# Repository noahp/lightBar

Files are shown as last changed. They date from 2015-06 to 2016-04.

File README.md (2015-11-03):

# lightBar
prototype in action  
Basic serial addressable WS2812B RGB LED banner. Comprised of multiple 12x7 modules.

# hardware
Ordered the boards from dirtypcbs.com, $25 shipped. I received 11 boards (1 bonus!), 22 days turn, pretty nice.  
The basic module contains 84 LEDs arranged in 7 rows of 12 each, and is designed to display 2 monospaced 5x7 pixel characters.  
Several 2-character modules can be connected together to create the full display.  

## schematic
[pdf view](https://github.com/noahp/lightBar/raw/master/hw/lightBar.pdf)

## pcb renders
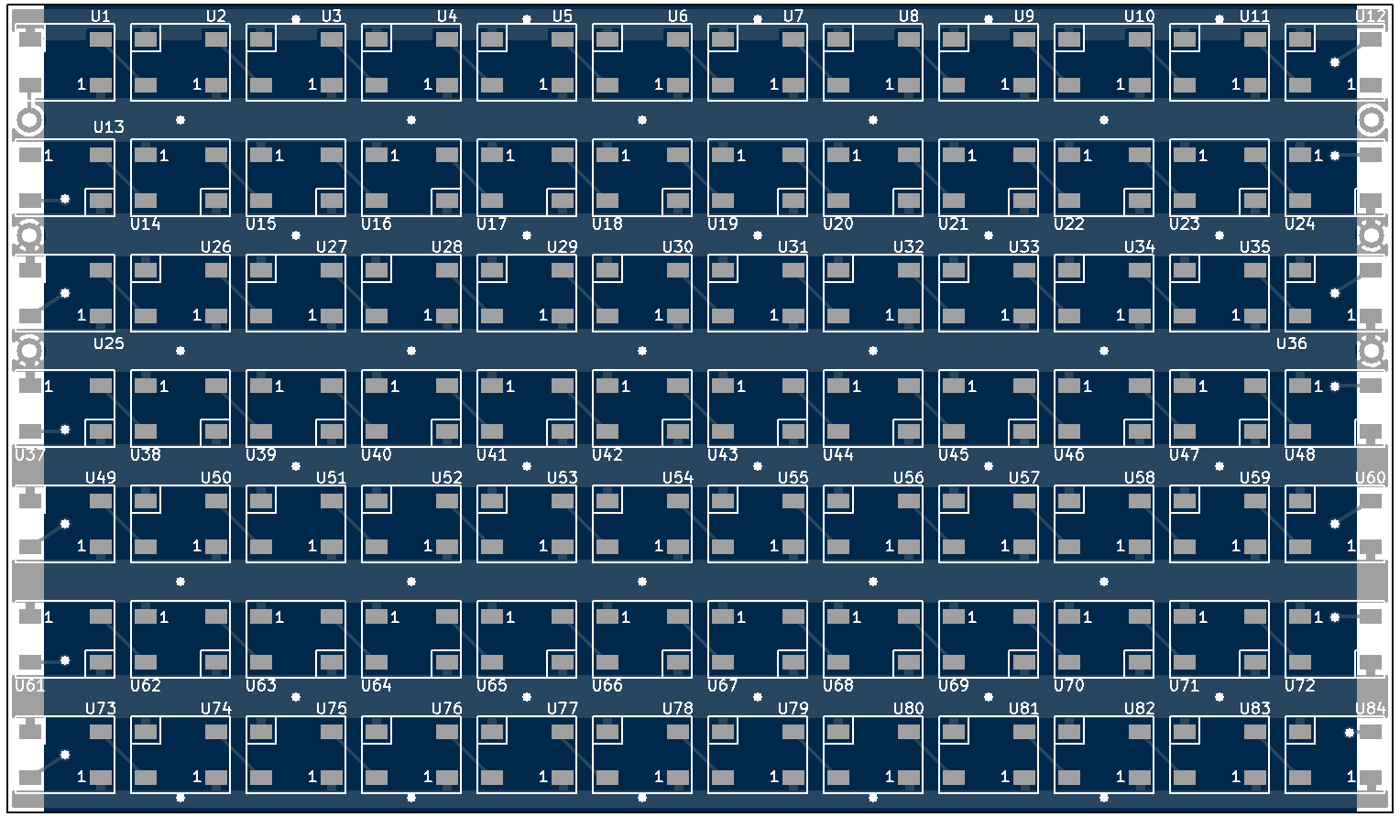
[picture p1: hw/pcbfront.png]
pcb front

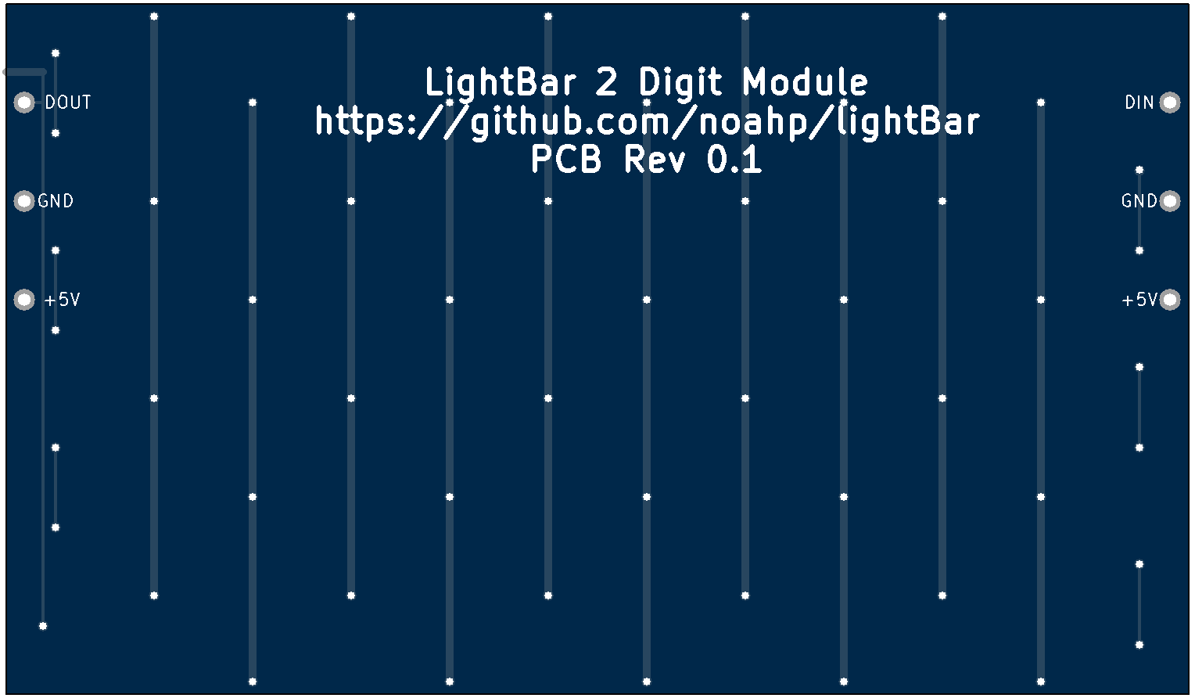
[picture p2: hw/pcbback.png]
pcb back
  

# software
My plan is to use some Cortex-M processor on the strip itself to do the real-time LED control (framebuffer + SPI transmission). Probably an ESP8266 wifi module (ESP-12) will be used as the interface for setting the displayed data.  
Some ideas-  
- get internet time/date and display it
- display weather, possibly using a gradient over the text background showing temperature/precip conditions

I'm thinking some simple description language (maybe JSON format) to transmit the content from the ESP8266 to the LED controller. Something that can describe text content and position, bitmaps, maybe transparency. The LED controller would parse this data into its bitmapped frame buffer and print it on the display.

For operation of the ESP8266, flow would be like this-  
`wakeup->connect to saved access point credentials (lua file system)`  
`    ->success, get time and date and weather information->sleep`  
`    ->failure after few seconds, switch to access point mode and serve simple web page form with 2 fields, for ssid + key->if HTTP POSTs new credentials->back to start (try to connect)`

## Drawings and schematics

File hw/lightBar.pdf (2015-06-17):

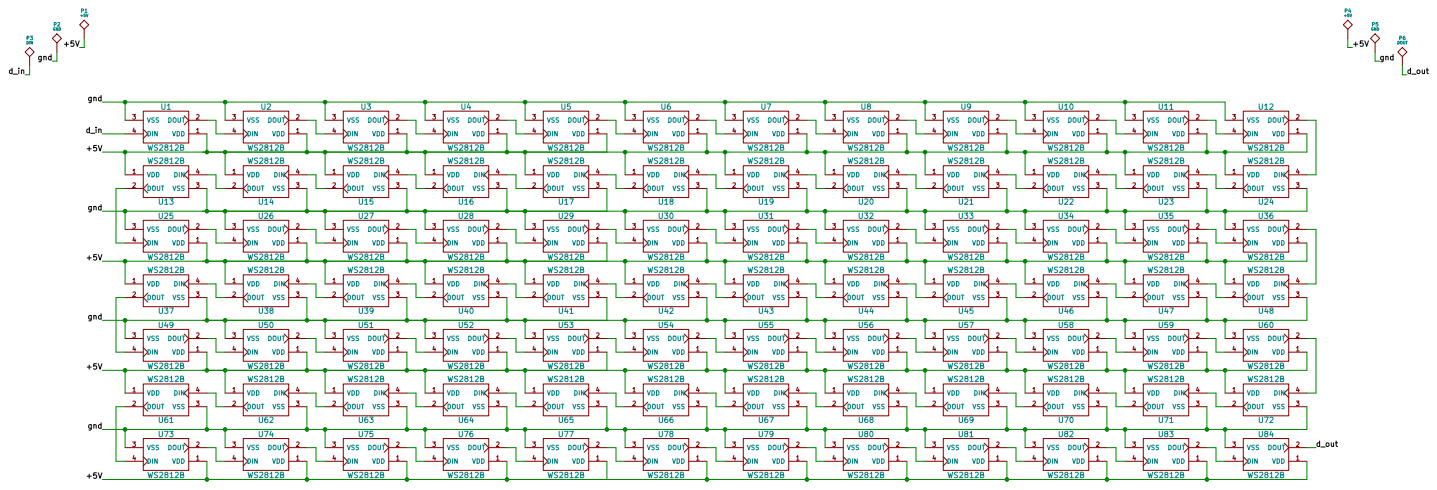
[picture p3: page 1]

File: lightBar.sch Sheet: /

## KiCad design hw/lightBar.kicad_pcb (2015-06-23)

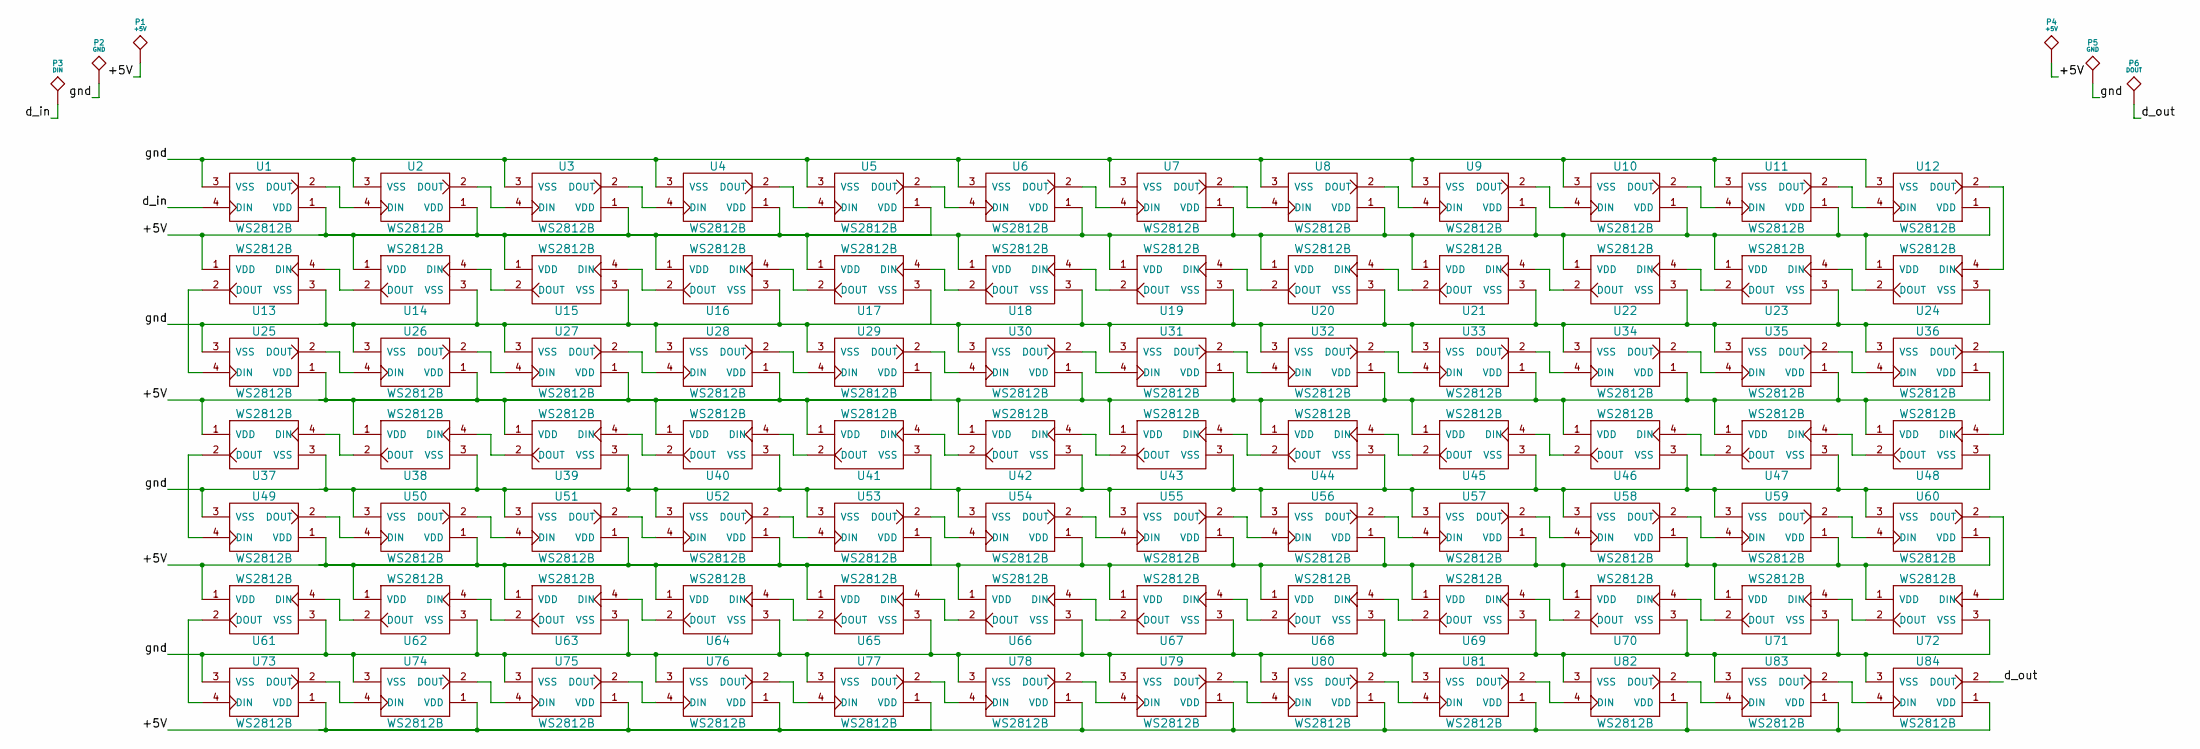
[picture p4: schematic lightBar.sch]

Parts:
P1, P4: +5V; TEST_0.100
P2, P5: GND; TEST_0.100
P3: DIN; TEST_0.100
P6: DOUT; TEST_0.100
U1, U2, U3, U4, U5, U6, U7, U8, U9, U10, U11, U12, U13, U14, U15, U16, U17, U18, U19, U20, U21, U22, U23, U24, U25, U26, U27, U28, U29, U30, U31, U32, U33, U34, U35, U36, U37, U38, U39, U40, U41, U42, U43, U44, U45, U46, U47, U48, U49, U50, U51, U52, U53, U54, U55, U56, U57, U58, U59, U60, U61, U62, U63, U64, U65, U66, U67, U68, U69, U70, U71, U72, U73, U74, U75, U76, U77, U78, U79, U80, U81, U82, U83, U84: WS2812B; WS2812B_SMD_5050

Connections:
/+5V: P1.1, P4.1, U1.1 (VDD), U2.1 (VDD), U3.1 (VDD), U4.1 (VDD), U5.1 (VDD), U6.1 (VDD), U7.1 (VDD), U8.1 (VDD), U9.1 (VDD), U10.1 (VDD), U11.1 (VDD), U12.1 (VDD), U13.1 (VDD), U14.1 (VDD), U15.1 (VDD), U16.1 (VDD), U17.1 (VDD), U18.1 (VDD), U19.1 (VDD), U20.1 (VDD), U21.1 (VDD), U22.1 (VDD), U23.1 (VDD), U24.1 (VDD), U25.1 (VDD), U26.1 (VDD), U27.1 (VDD), U28.1 (VDD), U29.1 (VDD), U30.1 (VDD), U31.1 (VDD), U32.1 (VDD), U33.1 (VDD), U34.1 (VDD), U35.1 (VDD), U36.1 (VDD), U37.1 (VDD), U38.1 (VDD), U39.1 (VDD), U40.1 (VDD), U41.1 (VDD), U42.1 (VDD), U43.1 (VDD), U44.1 (VDD), U45.1 (VDD), U46.1 (VDD), U47.1 (VDD), U48.1 (VDD), U49.1 (VDD), U50.1 (VDD), U51.1 (VDD), U52.1 (VDD), U53.1 (VDD), U54.1 (VDD), U55.1 (VDD), U56.1 (VDD), U57.1 (VDD), U58.1 (VDD), U59.1 (VDD), U60.1 (VDD), U61.1 (VDD), U62.1 (VDD), U63.1 (VDD), U64.1 (VDD), U65.1 (VDD), U66.1 (VDD), U67.1 (VDD), U68.1 (VDD), U69.1 (VDD), U70.1 (VDD), U71.1 (VDD), U72.1 (VDD), U73.1 (VDD), U74.1 (VDD), U75.1 (VDD), U76.1 (VDD), U77.1 (VDD), U78.1 (VDD), U79.1 (VDD), U80.1 (VDD), U81.1 (VDD), U82.1 (VDD), U83.1 (VDD), U84.1 (VDD)
/d_in: P3.1, U1.4 (DIN)
/d_out: P6.1, U84.2 (DOUT)
/gnd: P2.1, P5.1, U1.3 (VSS), U2.3 (VSS), U3.3 (VSS), U4.3 (VSS), U5.3 (VSS), U6.3 (VSS), U7.3 (VSS), U8.3 (VSS), U9.3 (VSS), U10.3 (VSS), U11.3 (VSS), U12.3 (VSS), U13.3 (VSS), U14.3 (VSS), U15.3 (VSS), U16.3 (VSS), U17.3 (VSS), U18.3 (VSS), U19.3 (VSS), U20.3 (VSS), U21.3 (VSS), U22.3 (VSS), U23.3 (VSS), U24.3 (VSS), U25.3 (VSS), U26.3 (VSS), U27.3 (VSS), U28.3 (VSS), U29.3 (VSS), U30.3 (VSS), U31.3 (VSS), U32.3 (VSS), U33.3 (VSS), U34.3 (VSS), U35.3 (VSS), U36.3 (VSS), U37.3 (VSS), U38.3 (VSS), U39.3 (VSS), U40.3 (VSS), U41.3 (VSS), U42.3 (VSS), U43.3 (VSS), U44.3 (VSS), U45.3 (VSS), U46.3 (VSS), U47.3 (VSS), U48.3 (VSS), U49.3 (VSS), U50.3 (VSS), U51.3 (VSS), U52.3 (VSS), U53.3 (VSS), U54.3 (VSS), U55.3 (VSS), U56.3 (VSS), U57.3 (VSS), U58.3 (VSS), U59.3 (VSS), U60.3 (VSS), U61.3 (VSS), U62.3 (VSS), U63.3 (VSS), U64.3 (VSS), U65.3 (VSS), U66.3 (VSS), U67.3 (VSS), U68.3 (VSS), U69.3 (VSS), U70.3 (VSS), U71.3 (VSS), U72.3 (VSS), U73.3 (VSS), U74.3 (VSS), U75.3 (VSS), U76.3 (VSS), U77.3 (VSS), U78.3 (VSS), U79.3 (VSS), U80.3 (VSS), U81.3 (VSS), U82.3 (VSS), U83.3 (VSS), U84.3 (VSS)
unnamed: U1.2 (DOUT), U2.4 (DIN)
unnamed: U2.2 (DOUT), U3.4 (DIN)
unnamed: U3.2 (DOUT), U4.4 (DIN)
unnamed: U4.2 (DOUT), U5.4 (DIN)
unnamed: U5.2 (DOUT), U6.4 (DIN)
unnamed: U6.2 (DOUT), U7.4 (DIN)
unnamed: U7.2 (DOUT), U8.4 (DIN)
unnamed: U8.2 (DOUT), U9.4 (DIN)
unnamed: U10.2 (DOUT), U11.4 (DIN)
unnamed: U9.2 (DOUT), U10.4 (DIN)
unnamed: U11.2 (DOUT), U12.4 (DIN)
unnamed: U12.2 (DOUT), U24.4 (DIN)
unnamed: U13.2 (DOUT), U25.4 (DIN)
unnamed: U13.4 (DIN), U14.2 (DOUT)
unnamed: U14.4 (DIN), U15.2 (DOUT)
unnamed: U15.4 (DIN), U16.2 (DOUT)
unnamed: U16.4 (DIN), U17.2 (DOUT)
unnamed: U17.4 (DIN), U18.2 (DOUT)
unnamed: U18.4 (DIN), U19.2 (DOUT)
unnamed: U19.4 (DIN), U20.2 (DOUT)
unnamed: U20.4 (DIN), U21.2 (DOUT)
unnamed: U21.4 (DIN), U22.2 (DOUT)
unnamed: U22.4 (DIN), U23.2 (DOUT)
unnamed: U23.4 (DIN), U24.2 (DOUT)
unnamed: U25.2 (DOUT), U26.4 (DIN)
unnamed: U26.2 (DOUT), U27.4 (DIN)
unnamed: U27.2 (DOUT), U28.4 (DIN)
unnamed: U28.2 (DOUT), U29.4 (DIN)
unnamed: U29.2 (DOUT), U30.4 (DIN)
unnamed: U30.2 (DOUT), U31.4 (DIN)
unnamed: U31.2 (DOUT), U32.4 (DIN)
unnamed: U32.2 (DOUT), U33.4 (DIN)
unnamed: U33.2 (DOUT), U34.4 (DIN)
unnamed: U34.2 (DOUT), U35.4 (DIN)
unnamed: U35.2 (DOUT), U36.4 (DIN)
unnamed: U36.2 (DOUT), U48.4 (DIN)
unnamed: U37.2 (DOUT), U49.4 (DIN)
unnamed: U37.4 (DIN), U38.2 (DOUT)
unnamed: U38.4 (DIN), U39.2 (DOUT)
unnamed: U39.4 (DIN), U40.2 (DOUT)
unnamed: U40.4 (DIN), U41.2 (DOUT)
unnamed: U41.4 (DIN), U42.2 (DOUT)
unnamed: U42.4 (DIN), U43.2 (DOUT)
unnamed: U43.4 (DIN), U44.2 (DOUT)
unnamed: U44.4 (DIN), U45.2 (DOUT)
unnamed: U45.4 (DIN), U46.2 (DOUT)
unnamed: U46.4 (DIN), U47.2 (DOUT)
unnamed: U47.4 (DIN), U48.2 (DOUT)
unnamed: U49.2 (DOUT), U50.4 (DIN)
unnamed: U50.2 (DOUT), U51.4 (DIN)
unnamed: U51.2 (DOUT), U52.4 (DIN)
unnamed: U52.2 (DOUT), U53.4 (DIN)
unnamed: U53.2 (DOUT), U54.4 (DIN)
unnamed: U54.2 (DOUT), U55.4 (DIN)
unnamed: U55.2 (DOUT), U56.4 (DIN)
unnamed: U56.2 (DOUT), U57.4 (DIN)
unnamed: U57.2 (DOUT), U58.4 (DIN)
unnamed: U58.2 (DOUT), U59.4 (DIN)
unnamed: U59.2 (DOUT), U60.4 (DIN)
unnamed: U60.2 (DOUT), U72.4 (DIN)
unnamed: U61.2 (DOUT), U73.4 (DIN)
unnamed: U61.4 (DIN), U62.2 (DOUT)
unnamed: U62.4 (DIN), U63.2 (DOUT)
unnamed: U63.4 (DIN), U64.2 (DOUT)
unnamed: U64.4 (DIN), U65.2 (DOUT)
unnamed: U65.4 (DIN), U66.2 (DOUT)
unnamed: U66.4 (DIN), U67.2 (DOUT)
unnamed: U67.4 (DIN), U68.2 (DOUT)
unnamed: U68.4 (DIN), U69.2 (DOUT)
unnamed: U69.4 (DIN), U70.2 (DOUT)
unnamed: U70.4 (DIN), U71.2 (DOUT)
unnamed: U71.4 (DIN), U72.2 (DOUT)
unnamed: U73.2 (DOUT), U74.4 (DIN)
unnamed: U74.2 (DOUT), U75.4 (DIN)
unnamed: U75.2 (DOUT), U76.4 (DIN)
unnamed: U76.2 (DOUT), U77.4 (DIN)
unnamed: U77.2 (DOUT), U78.4 (DIN)
unnamed: U78.2 (DOUT), U79.4 (DIN)
unnamed: U79.2 (DOUT), U80.4 (DIN)
unnamed: U80.2 (DOUT), U81.4 (DIN)
unnamed: U81.2 (DOUT), U82.4 (DIN)
unnamed: U82.2 (DOUT), U83.4 (DIN)
unnamed: U83.2 (DOUT), U84.4 (DIN)

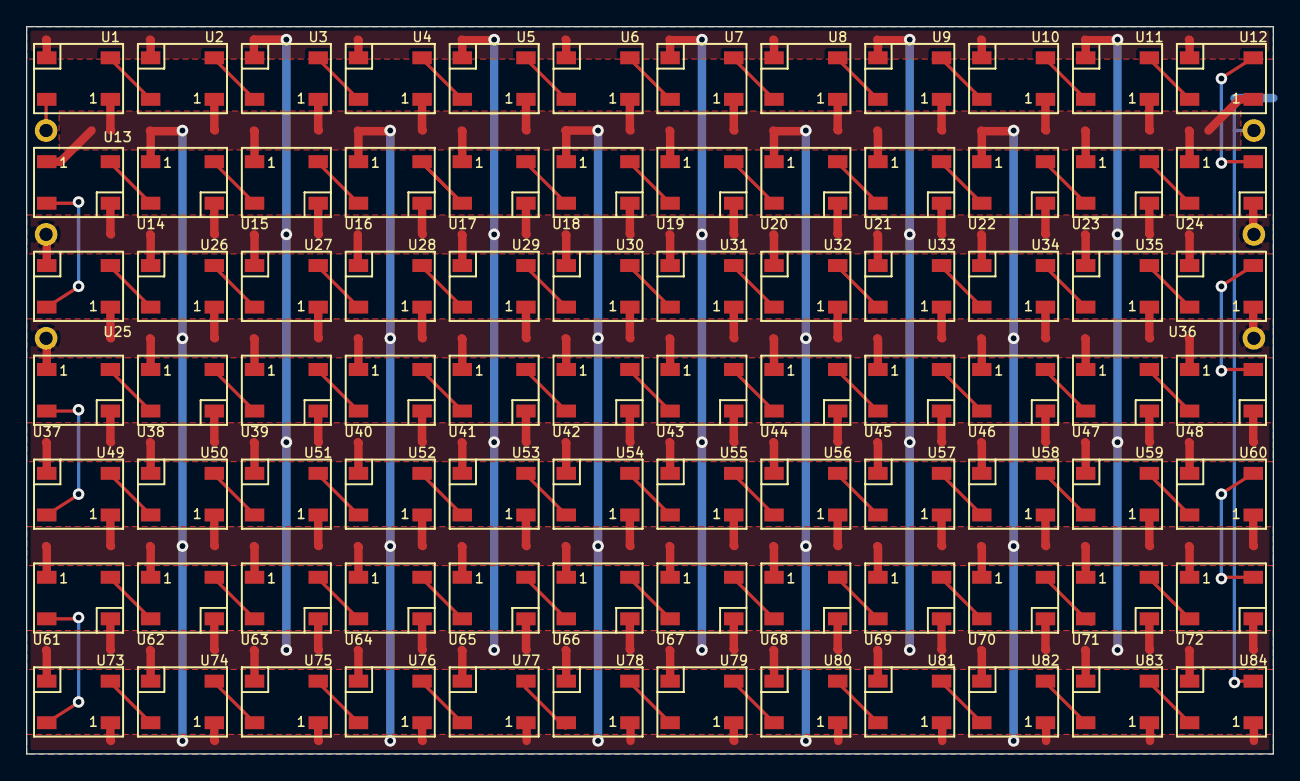
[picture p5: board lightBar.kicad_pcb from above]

Board: 2 copper layers, 96.0 x 56.0 mm, 90 parts (0 on the bottom side), 87 nets.

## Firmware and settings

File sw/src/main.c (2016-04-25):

#include "MKL26Z4.h"
#include "systick.h"
#include <string.h> // memset
#include "usb_main.h"
#include <stdlib.h> // strtoul
#include <stdbool.h>
#include "rgb_mgr.h"

#include <stdarg.h>
#include <stdio.h>
#include <stdlib.h>
#include <errno.h>

// makes heap go
caddr_t
_sbrk (int incr)
{
  extern char   end __asm ("end");
  extern char   heap_limit __asm ("__HeapLimit");
  static char * heap_end;
  char *        prev_heap_end;

  if (heap_end == NULL)
    heap_end = & end;

  prev_heap_end = heap_end;

  if (heap_end + incr > &heap_limit)
    {
#ifdef NIO_ENOMEM   //TODO: Update NIO error code for MQX
        errno = NIO_ENOMEM;
#else
        errno = ENOMEM;
#endif
      return (caddr_t) -1;
    }

  heap_end += incr;

  return (caddr_t) prev_heap_end;
}

// dead area, used as reset pulse in 1-wire ws2812 interface
#define SPI_DEAD_PULSE_LENGTH 260
static uint8_t spiData[SPI_DEAD_PULSE_LENGTH + 3 * 3 * RGB_MGR_PANEL_COUNT *
                       RGB_MGR_LEDS_PER_PANEL];

static void main_init_io(void)
{
  // init ports
  // disable COP
  SIM_COPC = 0;

  // enable clocks for PORTB
  SIM_SCGC5 |= SIM_SCGC5_PORTB_MASK;

  // set B0 to GPIO
  PORTB_PCR0 = PORT_PCR_MUX(1);

  // set output B0 low (LED on initially)
  GPIOB_PCOR = (1 << 0);

  // set B0 DDR to output
  GPIOB_PDDR |= (1 << 0);
}

// static void delay_ms(uint32_t ms)
// {
//    uint32_t start = systick_getms();
//    while(systick_getms() - start < ms);
// }

static void main_init_uart(void)
{
  uint32_t baud;

  // init uart0
  // enable clocks for port a and uart0
  SIM_SCGC5 |= SIM_SCGC5_PORTA_MASK;
  SIM_SCGC4 |= SIM_SCGC4_UART0_MASK;
  SIM_SOPT2 |= SIM_SOPT2_UART0SRC(1); // select MCGFLLCLK clock

  // configure io pins for uart0- alt 2
  PORTA_PCR1 = PORT_PCR_MUX(2);
  PORTA_PCR2 = PORT_PCR_MUX(2);

  // set output mode for TX, pa12
  GPIOA_PDDR |= (1 << 2);

  // set oversampling ratio to 25
  UART0_C4 = UART0_C4_OSR(25 - 1);

  // set baud rate to 9600
  baud      = (48000000 / 9600) / 25;            // <- baud = CLOCK /
                                                 // ((OSR+1)*BR)
  UART0_BDH = UART0_BDH_SBR((baud >> 8) & 0x1F); // upper 5 bits
  UART0_BDL = UART0_BDL_SBR(baud & 0xFF);        // lower 8 bits

  // turn on tx + rx
  UART0_C2 = UART0_C2_RE_MASK | UART0_C2_TE_MASK;

  //    // send a char?
  //    UART0_D = 'N';
}

static void main_init_spi(void)
{
  // init spi0
  // enable clocks for PORTC
  SIM_SCGC5 |= SIM_SCGC5_PORTC_MASK;

  // configure io pins for spi- alt 2
  // PTC4-5-6
  PORTC_PCR4 = PORT_PCR_MUX(2);
  PORTC_PCR5 = PORT_PCR_MUX(2);
  PORTC_PCR6 = PORT_PCR_MUX(2);

  // set pc6 to output-
  GPIOC_PDDR |= (1 << 6);

  // enable SPI0 module
  SIM_SCGC4 |= SIM_SCGC4_SPI0_MASK;

  // configure as master, cs output driven automatically, CPOL=1
  SPI0_C1 |= (SPI_C1_MSTR_MASK | SPI_C1_SSOE_MASK | SPI_C1_CPOL_MASK);
  SPI0_C2 |= SPI_C2_MODFEN_MASK;

  // select clock divider- SPPR = 0b010 (/3), SPR = 0b0010 (/8).
  // target baud rate is 2MHz
  SPI0_BR = SPI_BR_SPPR(0x4) | SPI_BR_SPR(0x0);

  // turn on spi
  SPI0_C1 |= SPI_C1_SPE_MASK;

  // now set up dma
  SIM_SCGC6 |= SIM_SCGC6_DMAMUX_MASK; // enable clocks
  SIM_SCGC7 |= SIM_SCGC7_DMA_MASK;

  // dma mux
  // disable dmamux0 & clear channel select
  DMAMUX0_BASE_PTR->CHCFG[0] &=
    ~(DMAMUX_CHCFG_ENBL_MASK | DMAMUX_CHCFG_SOURCE_MASK);

  // select channel 17 for spi tx & enable it
  DMAMUX0_BASE_PTR->CHCFG[0] |= DMAMUX_CHCFG_SOURCE(17) | DMAMUX_CHCFG_ENBL_MASK;

  // dma
  // set destination address register to the SPI tx register
  DMA_BASE_PTR->DMA[0].DAR = (uint32_t)&SPI0_DL;

  // configure DMA_0 for spi tx
  DMA_BASE_PTR->DMA[0].DCR = DMA_DCR_ERQ_MASK | // enable periph. request
                             DMA_DCR_CS_MASK |
                             DMA_DCR_SINC_MASK |
                             DMA_DCR_SSIZE(0x01) |
                             DMA_DCR_DSIZE(0x01) |
                             DMA_DCR_D_REQ_MASK;
}

static void main_spi_send(uint8_t *pData, uint32_t len)
{
  // wait until dma busy flag is cleared
  while (DMA_BASE_PTR->DMA[0].DSR_BCR & DMA_DSR_BCR_BSY_MASK) ;

  //    // pull spi mosi low (p27) for at least 50us
  //    PORTC_PCR6 = PORT_PCR_MUX(1);
  //    GPIOC_PCOR = (1 << 6);
  //    delay_ms(2);
  // reset dma
  DMA_BASE_PTR->DMA[0].DSR_BCR = DMA_DSR_BCR_DONE_MASK;

  // write to the dma
  DMA_BASE_PTR->DMA[0].SAR     = (uint32_t)pData;
  DMA_BASE_PTR->DMA[0].DSR_BCR = len & 0x00ffffff;

  // enable dma on the spi
  DMA_BASE_PTR->DMA[0].DCR |= DMA_DCR_ERQ_MASK;

  // PORTC_PCR6 = PORT_PCR_MUX(2);
  SPI0_C2 |= SPI_C2_TXDMAE_MASK;

  //    // wait until dma busy flag is cleared
  //    while(DMA_BASE_PTR->DMA[0].DSR_BCR & DMA_DSR_BCR_BSY_MASK);
}
#define DEFAULT_TIME_STR ("1200")
static char* main_get_time(void)
{
  static char ascii_time[sizeof(DEFAULT_TIME_STR)] = DEFAULT_TIME_STR;

  sprintf(ascii_time, "%2lu%02lu", (systick_getms() / 10 / 60 / 60) % 12,
          (systick_getms() / 10 / 60) % 60);

  return ascii_time;
}

static void main_led(void)
{
  static uint32_t blinkTime = 0;

  // blink every 250ms
  if (systick_getms() - blinkTime > 250) {
    blinkTime = systick_getms();

    // toggle
    GPIOB_PTOR = (1 << 0);
  }
}

static int main_poll_uart(uint8_t *pChr)
{
  if (UART0_S1 & UART0_S1_RDRF_MASK) {
    *pChr = UART0_D;
    return 1;
  }

  return -1;
}

int main(void)
{
  #define SIZE_OF_CHARBUF 16
  static uint32_t rgbTime = 0;
  uint8_t   charBuf[SIZE_OF_CHARBUF];
  uint8_t   settingCount;
  bool      settingActive = false;
  bool      inputActive   = false;
  uint8_t   rxData;
  int       gotCharacter = -1;
  rgbData_t tempColor;
  bool scrollactive = false, testactive = false, incrementactive = false;

  // initialize the necessary
  main_init_io();
  main_init_spi();
  main_init_uart();

  // rgb init
  memset(spiData, 0, sizeof(spiData));
  rgb_mgr_init(&spiData[SPI_DEAD_PULSE_LENGTH],
               sizeof(spiData) - SPI_DEAD_PULSE_LENGTH);
  rgb_mgr_set_new_str((uint8_t*)main_get_time(), sizeof(DEFAULT_TIME_STR) - 1);
  rgb_mgr_set_scroll(false);

  // usb init
  usb_main_init();

  while (1) {
    // led task
    main_led();

    // rgb task
    rgb_mgr_main_function();

    // refresh every 50 ms
    if (systick_getms() - rgbTime > 50) {
      rgbTime = systick_getms();
      main_spi_send(spiData, sizeof(spiData));
      rgb_mgr_set_new_str((uint8_t*)main_get_time(), sizeof(DEFAULT_TIME_STR) - 1);
    }

    // usb task
    gotCharacter = usb_main_mainfunction(&rxData);

    // check for incoming uart characters if nothing received on usb
    if (gotCharacter == -1) {
      gotCharacter = main_poll_uart(&rxData);
    }

    if (gotCharacter != -1) {
      if (settingActive) {
        switch (rxData) {
        case '\n':
        case '\r':
          settingActive         = false;
          charBuf[settingCount] = '\0';

          if (charBuf[0] == 'k') {
            rgb_mgr_set_brightness(strtoul((char *)&charBuf[1], NULL, 10));
          }
          break;

        case 'r':
          settingActive     = false;
          tempColor.all     = 0;
          tempColor.color.r = rgb_mgr_get_brightness();
          rgb_mgr_set_color(&tempColor);
          break;

        case 'g':
          settingActive     = false;
          tempColor.all     = 0;
          tempColor.color.g = rgb_mgr_get_brightness();
          rgb_mgr_set_color(&tempColor);
          break;

        case 'b':
          settingActive     = false;
          tempColor.all     = 0;
          tempColor.color.b = rgb_mgr_get_brightness();
          rgb_mgr_set_color(&tempColor);
          break;

        case 'i':
          settingActive = false;
          incrementactive = !incrementactive;
          rgb_mgr_set_increment(incrementactive);
          break;

        case 's':
          settingActive = false;
          scrollactive = !scrollactive;
          rgb_mgr_set_scroll(scrollactive);
          break;

        case 't':
          settingActive = false;
          testactive = !testactive;
          rgb_mgr_set_test(testactive);
          break;

        default:
          charBuf[settingCount++] = rxData;
          break;
        }
      }
      else if (inputActive) {
        switch (rxData) {
        case '\n':
        case '\r':
          inputActive = false;
          break;

        default:

          // enter character
          if (rgb_mgr_is_printable(rxData) && (settingCount < SIZE_OF_CHARBUF)) {
            charBuf[settingCount++] = rxData;
            rgb_mgr_set_new_str(charBuf, settingCount);
          }
          break;
        }
      }
      else {
        switch (rxData) {
        case 0x11 /* ctrl-q */:
          settingActive = true;
          settingCount  = 0;
          break;

        case 0x12 /* ctrl-r */:
          inputActive  = true;
          settingCount = 0;
          break;

        default:
          break;
        }
      }
    }
  }

  return 0;
}

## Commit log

2015-06-01 add kicad project + sch
    [rgb_banner.sch]
2015-06-01 add submodule kicadlib
2015-06-01 add 4x ws2812b to schematic
    [rgb_banner.sch]
2015-06-01 add pcb
    [rgb_banner.kicad_pcb]
2015-06-01 schematic pretty much done, start layout
    [digit1.sch, digit2.sch, rgb_banner.kicad_pcb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]
2015-06-01 work some on pcb, add trial image and link to 200 pcs ws2812b on aliexpress.
    [rgb_banner.kicad_pcb]
2015-06-01 start consolidating schematic
    [digit1.sch, rgb_banner.sch]
2015-06-03 pcb layout. zones not working.
    [rgb_banner.kicad_pcb, rgb_banner.sch]
2015-06-03 add test gerbers
    [rgb_banner.kicad_pcb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]
2015-06-03 zones not working
    [rgb_banner.kicad_pcb]
2015-06-03 zone fill by setting to no_net, filling, then setting correct net.
    [rgb_banner.kicad_pcb]
2015-06-03 remove "special" library??
    [rgb_banner.sch]
2015-06-10 work on pcb
    [rgb_banner.kicad_pcb, rgb_banner.sch]
2015-06-10 add gerbers, update the mockups a bit
    [rgb_banner.kicad_pcb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]
2015-06-10 add silks to the back
    [rgb_banner.kicad_pcb]
2015-06-19 save gerbers used in v0.1 dirtypcbs order
2015-06-23 fix some errors in the pcb- unconnected pads >_< change version silk to 2
    [lightBar-B_Cu.gbr, lightBar-B_Mask.gbr, lightBar-B_SilkS.gbr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]
2015-07-13 remove warning in usb code add 84-led buffer and fill them all with the same color/brightness
2015-07-15 scanPos to unsigned int so we don't set the previous led to zero and clearing scan mode will set the first led on
2015-07-15 rework how config works; now hit ctrl-q then the config values
    [main.c]
2015-07-16 add pcb renders from dirtypcbs
2015-07-16 change driver to x,y addressing, much better
2015-07-22 try to get uart0 working, no dice
2015-07-22 fix pinouts for uart0 init, works now.
    [main.c]
2015-07-22 process input from UART0 same as USB
2015-08-04 set test mode to default, fix some errors, add 2nd panel
    [main.c]
2015-10-21 add pumpkin image
2015-10-22 some changes to get scrolling to work more correctly. not perfect but functional. seasonal too!
    [main.c]
2016-04-25 rework some stuff. add sbrk implementation. clock mode sortof.
    [main.c]
